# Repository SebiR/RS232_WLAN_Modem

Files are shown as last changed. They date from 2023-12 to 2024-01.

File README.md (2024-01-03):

# RS232 WLAN Modem
An ESP8266 based device to emulate an old serial modem to get old hardware connected to the internet

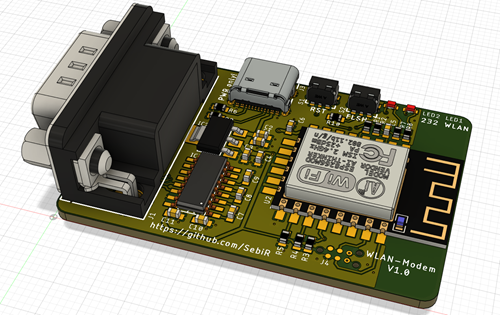
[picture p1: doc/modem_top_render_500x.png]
Modem


## Features
* USB-C power
* Can be used with male and female DSUB connectors
* Small form factor

## Uses
The board was intended to be used as a RS232 modem replacement for an old PC. But with the right firmware it can of course be used for other stuff:
* Wireless RS232 bridge
* IoT/Tasmota/MQT bridge for RS232 defices
* ...

# 3D printed case
There's also a case for 3D printing available!

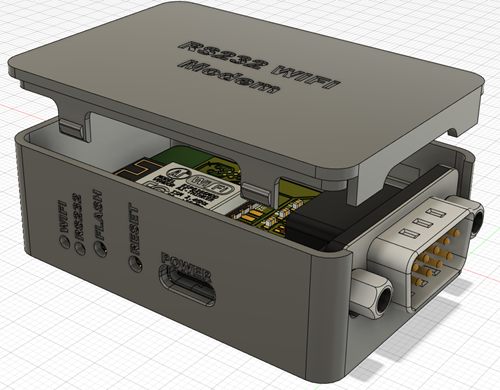
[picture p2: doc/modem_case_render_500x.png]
Modem


# Firmware and acknowledgement
The whole device is based on the RS232 Serial WIFI Modem from The Old Net.
The firmware can be found here: https://github.com/ssshake/vintage-computer-wifi-modem

I just wanted to create a more compact version of the hardware.

# Notes
The PCB has plated slots for the USB-C connector. The outline layer in the gerber files has a note for this. You might want to have an eye on the production files if you order the PCBs.

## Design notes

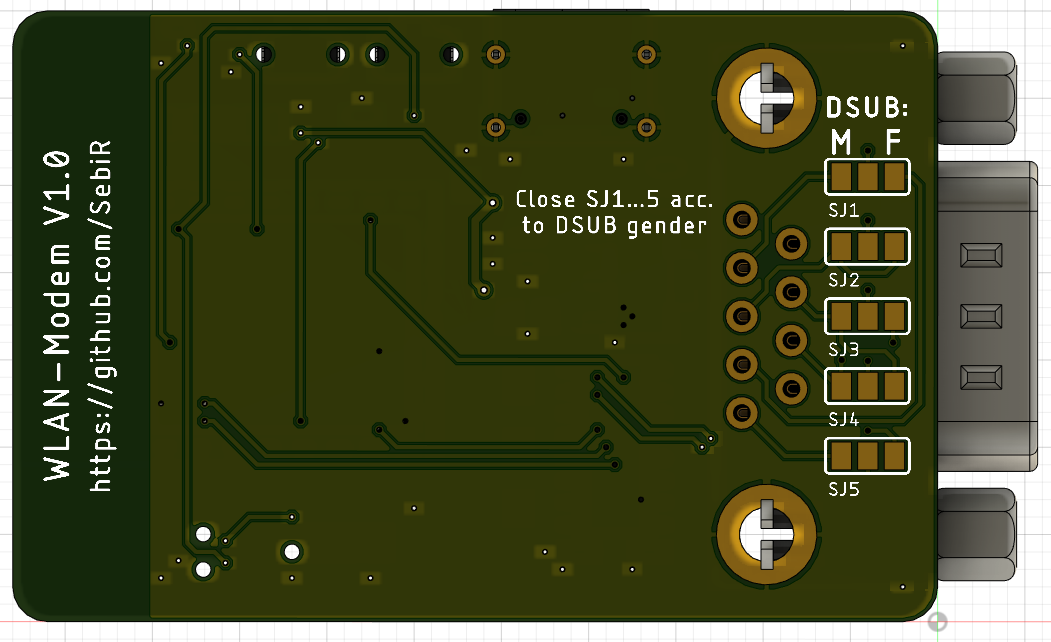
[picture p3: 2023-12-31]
doc/modem_bot_render.png

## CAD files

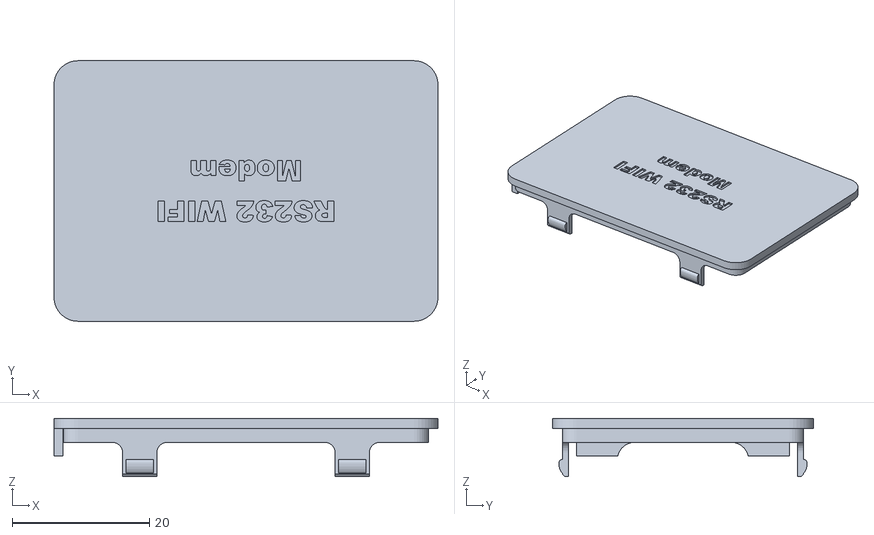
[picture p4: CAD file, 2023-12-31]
3d_case/modem_case_lid.stl
56.0 x 38.0 x 8.50

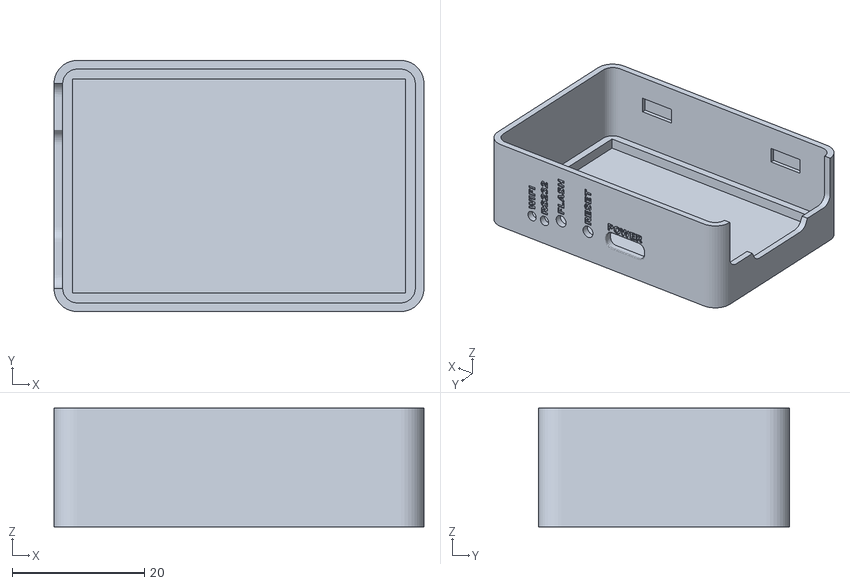
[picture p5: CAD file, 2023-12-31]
3d_case/modem_case_base.stl
56.0 x 38.0 x 18.0

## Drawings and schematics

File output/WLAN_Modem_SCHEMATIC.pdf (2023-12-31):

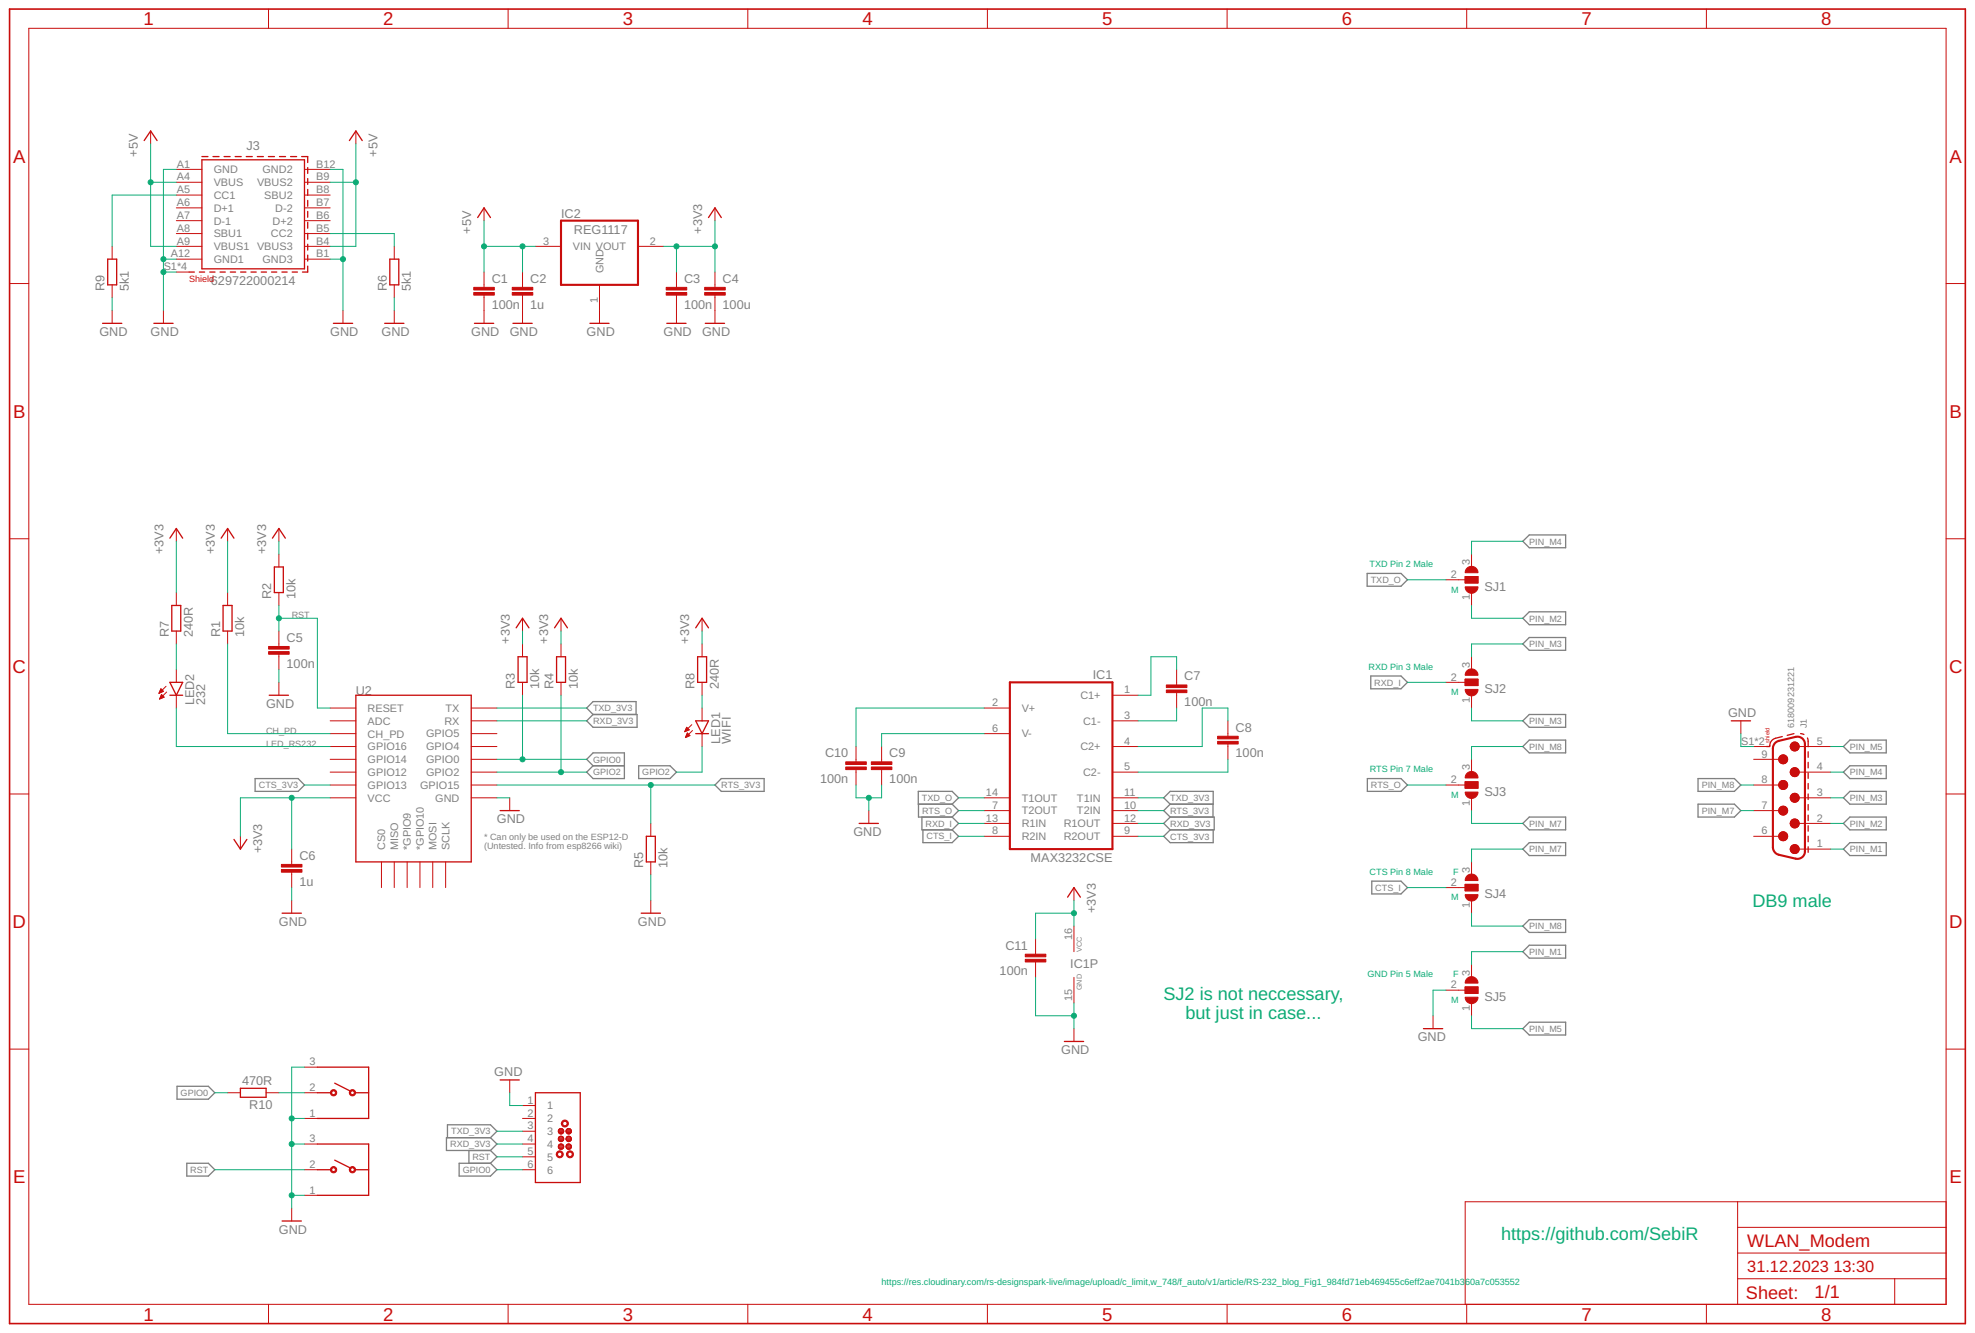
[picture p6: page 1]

* Can only be used on the ESP12-D
(Untested. Info from esp8266 wiki)

SJ2 is not neccessary, but just in case...

https://github.com/SebiR

https://res.cloudinary.com/rs-designspark-live/image/upload/c_limit,w_748/f_auto/v1/article/RS-232_blog_Fig1_984fd71eb469455c6eff2ae7041b360a7c053552

Sheet: 1/1

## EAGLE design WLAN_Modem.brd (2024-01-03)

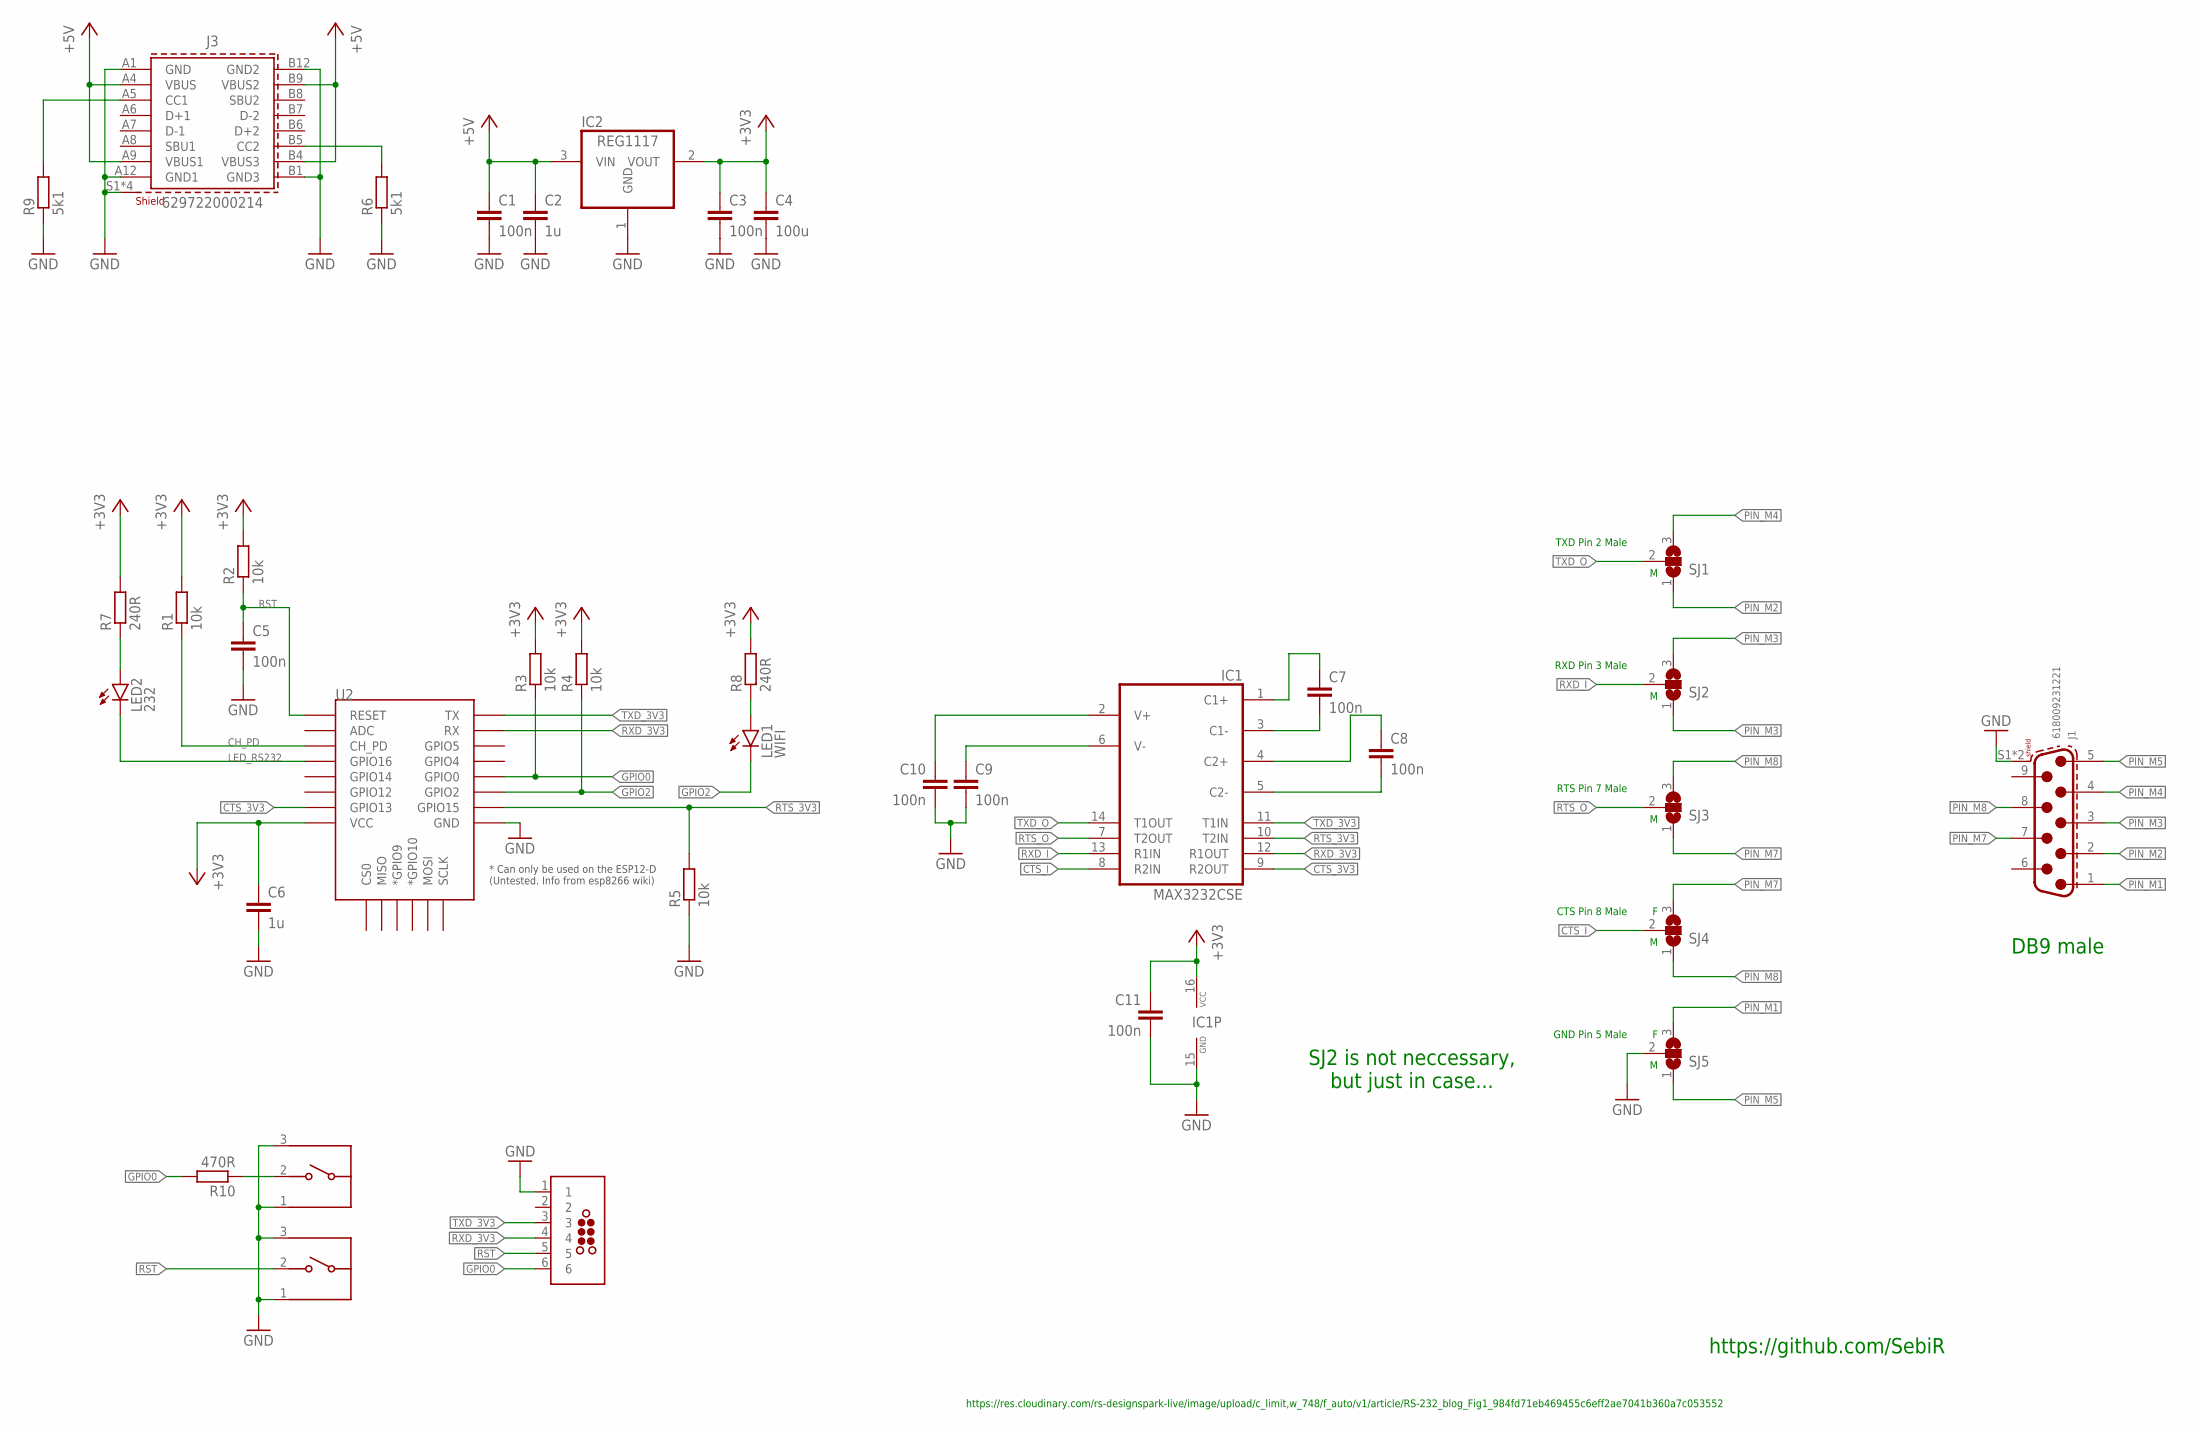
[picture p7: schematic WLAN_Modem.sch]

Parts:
C1, C3, C5, C7, C8, C9, C10, C11: 100n; C0603
C2, C6: 1u; C0603
C4: 100u; C0603
IC1: MAX3232CSE; SO16
IC2: REG1117; SOT223
J1: 618009231221
J3: 629722000214
J4: TAG-CONNECT_TC2030-MCP-NL
LED1: WIFI; CHIP-LED0603
LED2: 232; CHIP-LED0603
R1, R2, R3, R4, R5: 10k; R0603
R6, R9: 5k1; R0603
R7, R8: 240R; R0603
R10: 470R; R0603
S1, S2: 436333033816
SJ1, SJ2, SJ3, SJ4, SJ5: SJ2W; SJ_2
U2: ESP12ESMD; ESP12E-SMD

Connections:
2: J4.2
+3V3: C3.1, C4.1, C6.1, C11.1, IC1.16 (VCC), IC2.2 (VOUT), R1.2, R2.2, R3.2, R4.2, R7.2, R8.2, U2.VCC
+5V: C1.1, C2.1, IC2.3 (VIN), J3.A4 (VBUS), J3.A9 (VBUS1), J3.B4 (VBUS3), J3.B9 (VBUS2)
CH_PD: R1.1, U2.CH_PD
CTS_3V3: IC1.9 (R2OUT), U2.GPIO13
CTS_I: IC1.8 (R2IN), SJ4.2
GND: C1.2, C2.2, C3.2, C4.2, C5.2, C6.2, C9.2, C10.2, C11.2, IC1.15 (GND), IC2.1 (GND), J1.S1 (SHIELD), J1.S2 (SHIELD), J3.A1 (GND), J3.A12 (GND1), J3.B1 (GND3), J3.B12 (GND2), J3.S1 (SHIELD), J3.S2 (SHIELD), J3.S3 (SHIELD), J3.S4 (SHIELD), J4.1, R5.1, R6.1, R9.1, S1.1, S1.3, S2.1, S2.3, SJ5.2, U2.GND
GPIO0: J4.6, R3.1, R10.2, U2.GPIO0
GPIO2: LED1.C, R4.1, U2.GPIO2
LED_RS232: LED2.C, U2.GPIO16
unnamed: LED1.A, R8.1
unnamed: J3.A5 (CC1), R9.2
unnamed: LED2.A, R7.1
unnamed: J3.B5 (CC2), R6.2
unnamed: R10.1, S2.2
unnamed: C7.2, IC1.3 (C1-)
unnamed: C7.1, IC1.1 (C1+)
unnamed: C8.1, IC1.4 (C2+)
unnamed: C8.2, IC1.5 (C2-)
unnamed: C10.1, IC1.2 (V+)
unnamed: C9.1, IC1.6 (V-)
PIN_M1: J1.1, SJ5.3
PIN_M2: J1.2, SJ1.1
PIN_M3: J1.3, SJ2.1, SJ2.3
PIN_M4: J1.4, SJ1.3
PIN_M5: J1.5, SJ5.1
PIN_M7: J1.7, SJ3.1, SJ4.3
PIN_M8: J1.8, SJ3.3, SJ4.1
RST: C5.1, J4.5, R2.1, S1.2, U2.RESET
RTS_3V3: IC1.10 (T2IN), R5.2, U2.GPIO15
RTS_O: IC1.7 (T2OUT), SJ3.2
RXD_3V3: IC1.12 (R1OUT), J4.4, U2.RXD0 (RX)
RXD_I: IC1.13 (R1IN), SJ2.2
TXD_3V3: IC1.11 (T1IN), J4.3, U2.TXD0 (TX)
TXD_O: IC1.14 (T1OUT), SJ1.2

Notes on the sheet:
GND Pin 5 Male
CTS Pin 8 Male
RTS Pin 7 Male
RXD Pin 3 Male
TXD Pin 2 Male
https://res.cloudinary.com/rs-designspark-live/image/upload/c_limit,w_748/f_auto/v1/article/RS-232_blog_Fig1_984fd71eb469455c6eff2ae7041b360a7c053552
SJ2 is not neccessary, but just in case...
DB9 male
https://github.com/SebiR

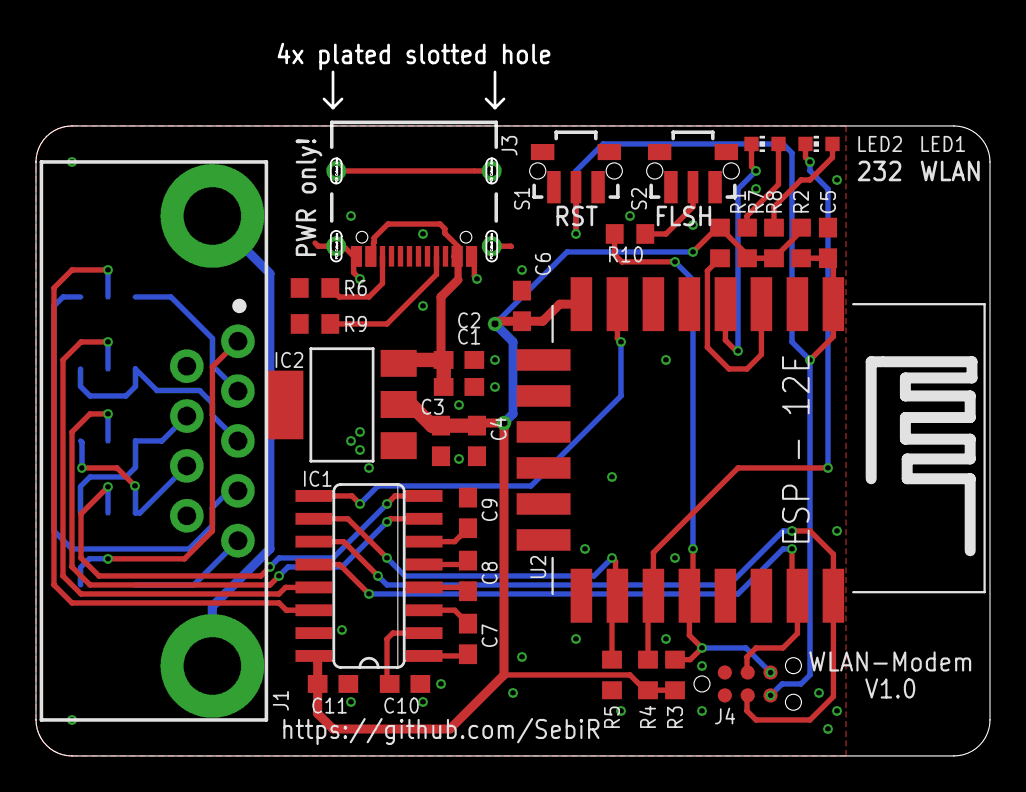
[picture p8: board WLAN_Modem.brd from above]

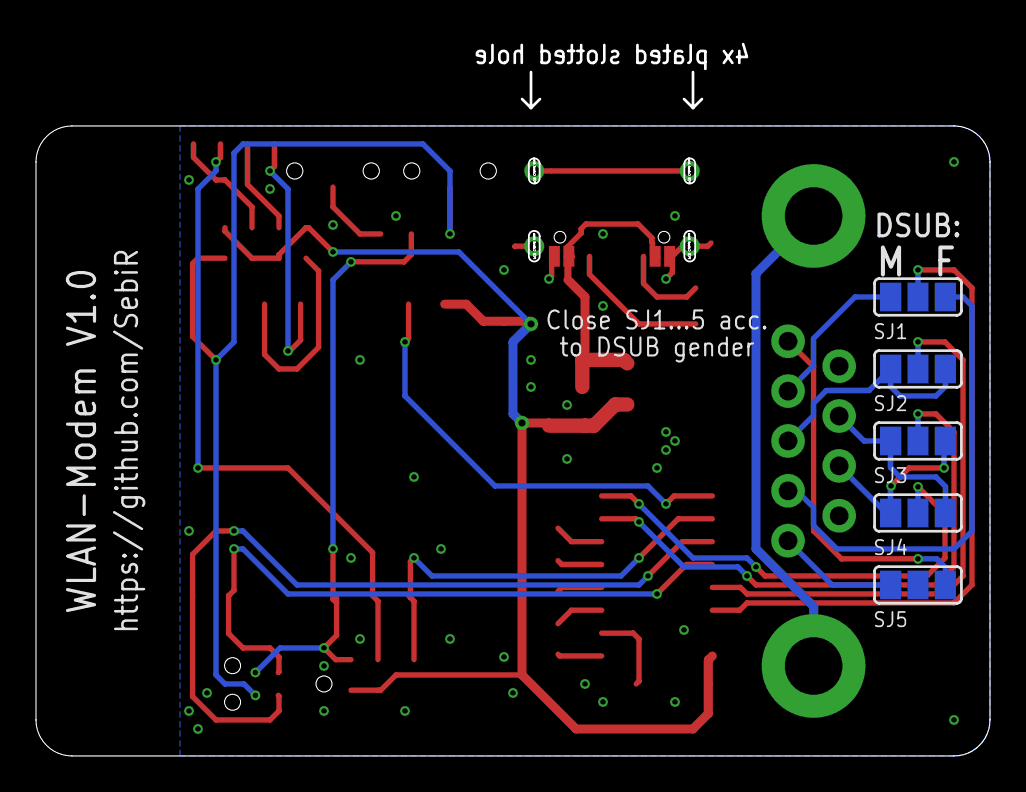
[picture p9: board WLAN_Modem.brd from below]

Board: 2 copper layers, 53.0 x 38.0 mm, 36 parts (5 on the bottom side), 34 nets.

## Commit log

2023-12-31 added stl files for the case
    [modem_case_base.stl, modem_case_lid.stl]
2024-01-03 * Optimized layout for manufacturing * Added plated slot note on dimension layer * Updated README.md * Added GERBER files
    [WLAN_Modem.brd]

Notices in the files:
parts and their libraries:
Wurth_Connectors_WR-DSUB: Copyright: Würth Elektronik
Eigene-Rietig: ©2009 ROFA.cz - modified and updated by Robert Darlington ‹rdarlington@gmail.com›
